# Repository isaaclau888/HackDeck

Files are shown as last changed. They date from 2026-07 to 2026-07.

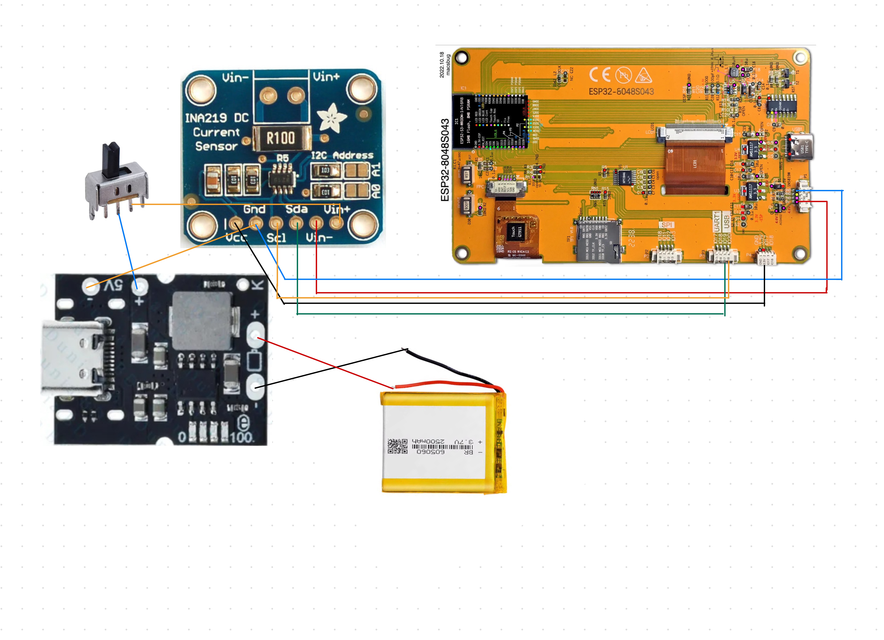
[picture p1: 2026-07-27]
HackDeck Wiring Diagram/HackDeck Wiring Diagram.JPG

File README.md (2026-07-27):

# HackDeck
HackDeck_2026-Jul-26_08-19-04PM-000_CustomizedView14507058763_png

HackDeck is a pocket-sized ESP32 touchscreen tool for testing hardware and checking pinouts.
Firstly, it shows live stats like displays your team’s GitHub updates, Slack messages, and project statuses.
Secondly, it serves as a quick hardware pinout reference and component tester for your workbench.
And last but not least, it lets you touch control custom web/GML tools or games you write for it.

unfold-hackdeck

## How to build it?
Please print all the 3D parts. <p>
螢幕截圖 2026-07-27 上午5 39 52

## How to assemble all the parts?
First, place the screen body down. <p>
螢幕截圖 2026-07-27 上午5 42 49

Secondly, follow the wiring diagram and wire the parts. <p>


1. IP5306 Power Module
 * BAT+: Connect to the Red wire from your LiPo Battery. 
 * BAT-: Connect to the Black wire from your LiPo Battery. 
 * OUT+: Connect to Pin 2 (Middle Pin) of the SS12D07 Slide Switch. (Use 28 AWG wire)
 * OUT-: Connect to GND on the INA219 module. (Use 28 AWG wire)
2. SS12D07 Slide Switch
 * Pin 2 (Middle Pin): Connect to OUT+ on the IP5306 module. (Use 28 AWG wire)
 * Pin 1 or 3 (Side Pin): Connect to VIN+ on the INA219 module. (Use 28 AWG wire)
3. INA219 Sensor Module
 * VIN+: Connect to the Side Pin of the SS12D07 Slide Switch. (Use 28 AWG wire)
 * VIN-: Connect to Port P1, Pin 1 (5V) on the ESP32 board. (Use PicoBlade cable)
 * GND: Connect to OUT- on the IP5306 and to Port P1, Pin 4 (GND) on the ESP32 board. (Use PicoBlade cable)
 * VCC: Connect to Port P4, Pin 2 (3.3V) on the ESP32 board. (Use PicoBlade cable)
 * SDA: Connect to Port P3, Pin 3 (IO19) on the ESP32 board. (Use PicoBlade cable)
 * SCL: Connect to Port P3, Pin 4 (IO20) on the ESP32 board. (Use PicoBlade cable)
4. ESP32-8048S043 Display Board
 * Port P1 (Bottom Centre, next to USB-C):
   * Pin 1 (5V): Wire coming from VIN- on the INA219 module.
   * Pin 4 (GND): Wire coming from GND on the INA219 module.
 * Port P4 (Bottom Left Corner):
   * Pin 2 (3.3V): Wire going to VCC on the INA219 module.
 * Port P3 (Middle Left Edge):
   * Pin 3 (IO19): Wire going to SDA on the INA219 module.
   * Pin 4 (IO20): Wire going to SCL on the INA219 module.
     
Thirdly, place the screen inside the screen body and the parts inside the body. <p>
螢幕截圖 2026-07-27 上午5 54 52

Then, get the screws inside the 4 holes. <p>
螢幕截圖 2026-07-27 上午5 56 02

After that, get the back cover and put it at the back. And also stick the switch and USB-C port out.
螢幕截圖 2026-07-27 上午5 57 08

Finally, you got a complete build.

## How can you use it?
1. Install Arduino IDE
   Download and install the latest version of Arduino IDE from the official Arduino website (https://www.arduino.cc/en/software).
2. Add ESP32 Board Support
   * Open Arduino IDE and go to File > Preferences.
   * In the Additional Boards Manager URLs field, add:
     https://raw.githubusercontent.com/espressif/arduino-esp32/gh-pages/package_esp32_index.json
   * Go to Tools > Board > Boards Manager, search for "ESP32" (by Espressif Systems), and click Install.
3. Install Required Libraries
   * Open the Library Manager (click the book stack icon on the left sidebar).
   * Search for and install the following libraries:
     * LovyanGFX
     * TAMC_GT911
     * ArduinoJson
 4. Configure Board Settings
   - Go to Tools > Board > esp32 > ESP32S3 Dev Module.
   - Configure the following under Tools:
     * USB CDC On Boot: Enabled
     * PSRAM: OPI PSRAM
     * Flash Size: 16MB (128Mb)
     * Partition Scheme: Huge APP (3MB No OTA) or 16M Flash
   - Connect your board via USB-C and select the correct port under Tools > Port.
 5. Upload Firmware
   * Open firmware/HackDeck.ino in Arduino IDE.
   * Update WIFI_SSID, WIFI_PASS, and your webhook URLs at the top of the sketch.
   * Click the Upload button.
 6. You're All Set!
   Once uploading finishes, the board will automatically reboot directly into your desktop control surface!

## Why did I make it?
I decided to make it because I needed a pocket-sized workbench assistant to stop switching tabs and hunting down pinout sheets while prototyping. It puts a live I2C scanner, pinout guide, GitHub feed, and macro buttons right on my desk.

## How I made it?
I designed the custom case using Fusion 360, programmed the firmware in Arduino IDE, and assembled the hardware using the ESP32 screen, IP5306 power management chip, SS12D07 power switch, INA219 current sensor, and a LiPo battery.

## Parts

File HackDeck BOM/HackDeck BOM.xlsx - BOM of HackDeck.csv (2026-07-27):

Description | Item | Usage Count | Purchase Quantity | Unit Price | Subtotal | Price(HKD) [$] | Price(RMB) [$] | Price(USD) [$] | Link | Additional description
Electrical Components
ESP32-8048S043 Display Board |  | 1 | 1 | $167.91 | $167.91 | $167.91 | $145.00 | $21.41 | https://mobile.yangkeduo.com/goods1.html?ps=A4UVhwHh6D
IP5306 Power Module |  | 1 | 1 | $1.68 | $1.68 | $1.68 | $1.45 | $0.21 | https://item.taobao.com/item.htm?id=874907024042&skuId=5709605800856
SS12D07 Slide Switch |  | 1 | 1 | $0.95 | $0.95 | $0.95 | $0.82 | $0.12 | https://item.taobao.com/item.htm?id=568771505825&skuId=6130758858583
INA219 Sensor Module |  | 1 | 1 | $4.59 | $4.59 | $4.59 | $3.96 | $0.58 | https://item.taobao.com/item.htm?id=953659389861
605060 LiPo Battery |  | 1 | 1 | $25.24 | $25.24 | $25.24 | $21.80 | $3.22 | https://item.taobao.com/item.htm?id=578582658189&xxc=shop&skuId=3832117712703
MX1.25 4-Pin Single-End Connector Wire |  | 4 | 1 | $3.13 | $3.13 | $3.13 | $2.70 | $0.40 | https://detail.tmall.com/item.htm?id=576790821801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
28 AWG Wire |  | 1 | 1 | $0.86 | $0.86 | $0.86 | $0.74 | $0.11 | https://detail.tmall.com/item.htm?id=673000932001&xxc=shop&skuId=5022668155483
 |  |  |  | Total |  | $204.36 | $176.47 | $26.05

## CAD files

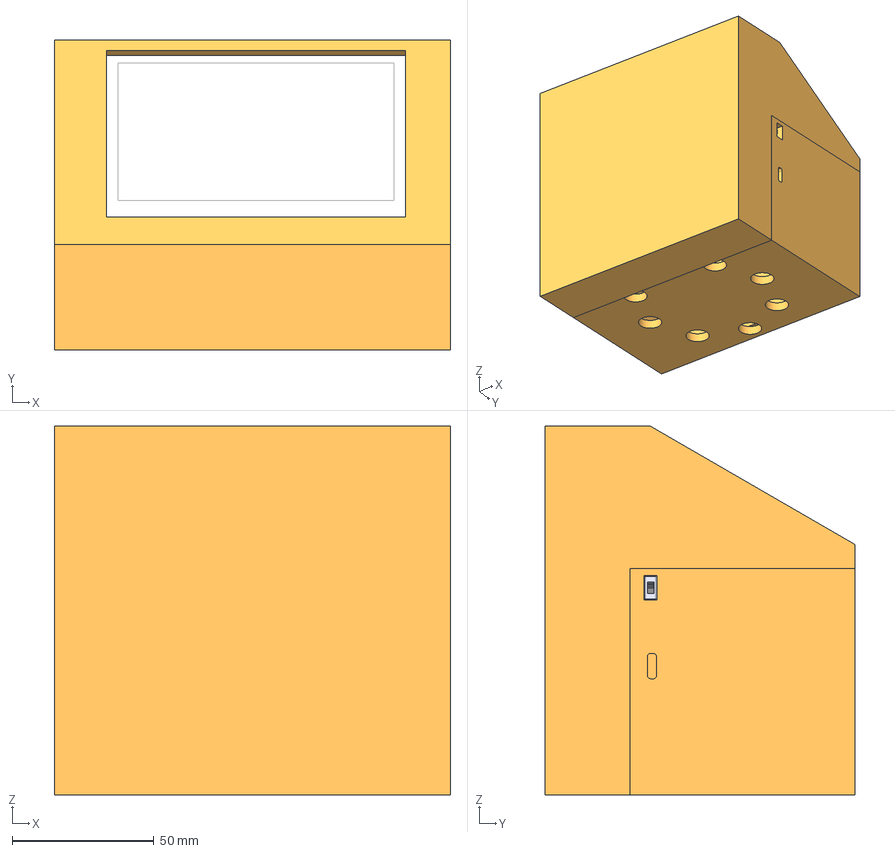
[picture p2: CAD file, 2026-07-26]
HackDeck STEP Files/HackDeck Assembly.step
139.9 x 109.5 x 130.2 mm
Electronics
Screen
Przetwornica 5V 2A
SS12D07VG4
INA219_I2C_IV_SENSOR
605060 LiPo Battery

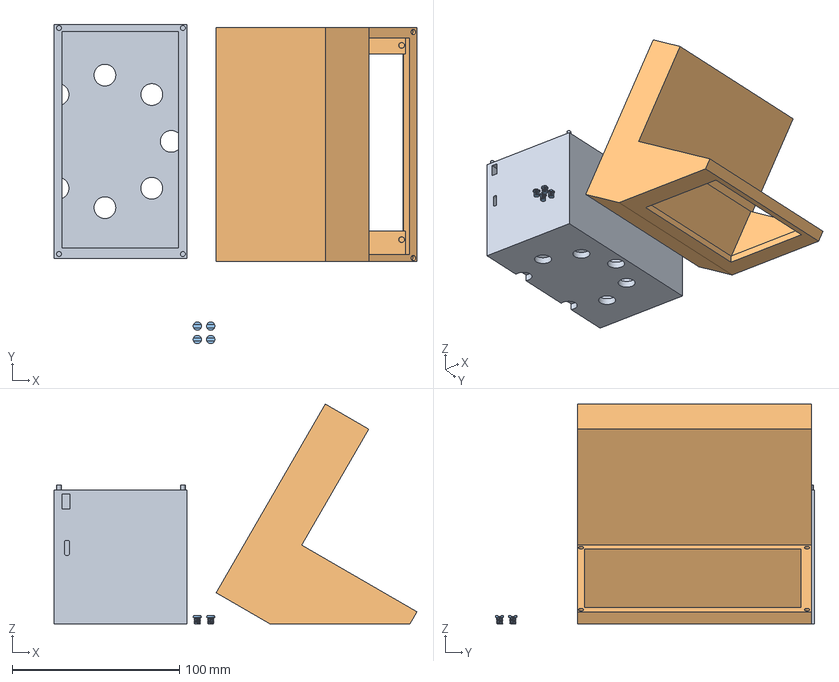
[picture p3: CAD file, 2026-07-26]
HackDeck 3mf File/HackDeck.3mf
216.8 x 190.7 x 131.4 mm
HackDeck Back Case.step
HackDeck Screen Body.step
HackDeck Screws.step

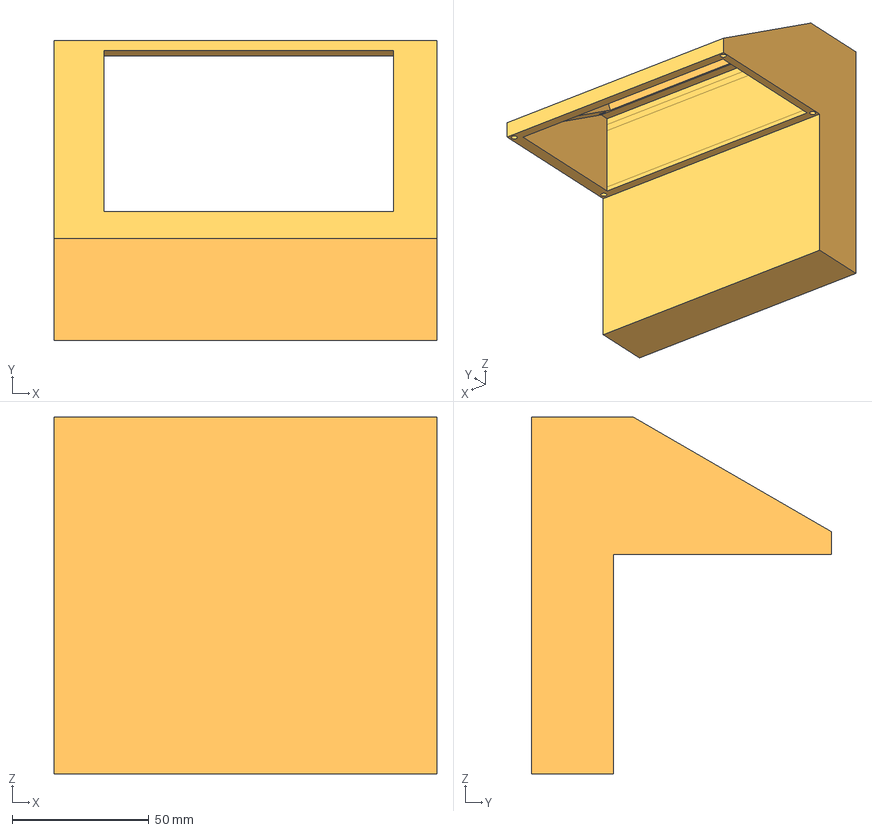
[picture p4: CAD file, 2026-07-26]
HackDeck STEP Files/HackDeck Screen Body.step
139.9 x 109.5 x 130.2 mm

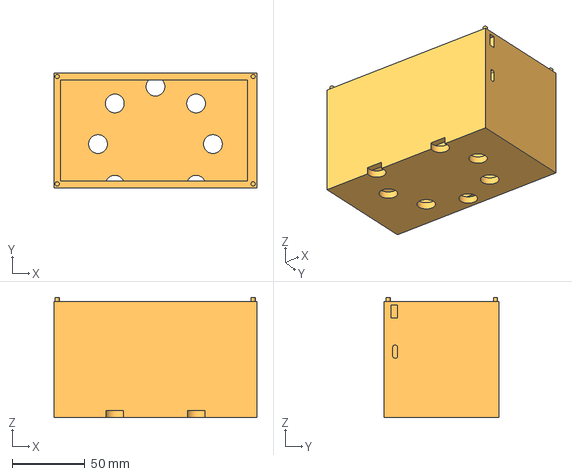
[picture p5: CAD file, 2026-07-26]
HackDeck STEP Files/HackDeck Back Case.step
139.9 x 79.5 x 83.0 mm

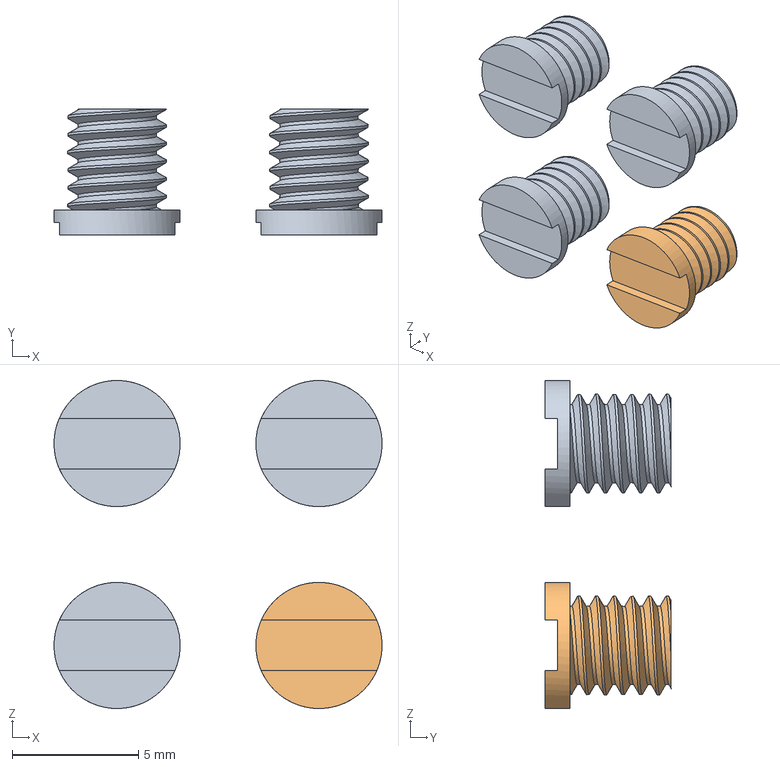
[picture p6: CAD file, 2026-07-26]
HackDeck STEP Files/HackDeck Screws.step
13.0 x 5.00 x 13.0 mm

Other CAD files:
HackDeck F3D/HackDeck.f3z

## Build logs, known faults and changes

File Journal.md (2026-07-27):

## 27/7/2026
I did a lot of work on the same day, spending 4-5 hours building this prototype or maybe the final build? <p>
HackDeck_2026-Jul-26_08-19-04PM-000_CustomizedView14507058763_png 

So why I decided to make this is because I needed a pocket-sized workbench assistant to stop switching tabs and hunting down pinout sheets while prototyping. It puts a live I2C scanner, pinout guide, GitHub feed, and macro buttons right on my desk. <p>

To make this, I made the case in Fusion, and I got all the STEP files of the parts on the Internet. Finding the parts on Google is tough; I need to think which parts I need and which parts I don't need. <p>
螢幕截圖 2026-07-27 上午11 15 11

After I made the case, I did the wiring diagram, and it looks like this: <p>
HackDeck Wiring Diagram
It doesn't look bad anyway. <p>

After making the wiring diagram, I have to do the BOM. I found the parts on Taobao. <p>
螢幕截圖 2026-07-27 上午11 17 45

Then, for the STEP files and the F3D, I exported them and put them in files. <p>
螢幕截圖 2026-07-27 上午11 19 40

For printing the parts, I imported the STEP files into the 3mf file for me to print them out on my 3D printer. <p>
螢幕截圖 2026-07-27 上午5 39 52

Last but not least, I dealt with README.md and Journal.md. This is the Journal.md that you are reading, and the README.md is on the front page of this repo. <p>
螢幕截圖 2026-07-27 上午11 22 26

What I did wrong was that when I was making the screws, I forgot to click the modelled button, and after I imported it to Bambu Studio, it didn't show the curves. <p>
螢幕截圖 2026-07-27 上午11 23 38

This is what I did today.

Total Time: 6 hours and 10 mins
https://lapse.hackclub.com/timelapse/nYyScDbP78Ud

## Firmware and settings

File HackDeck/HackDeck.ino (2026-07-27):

#include <Arduino.h>
#include <Wire.h>
#include <WiFi.h>
#include <TAMC_GT911.h>

#define LGFX_USE_V1
#include <LovyanGFX.hpp>
#include <lgfx/v1/platforms/esp32s3/Panel_RGB.hpp>
#include <lgfx/v1/platforms/esp32s3/Bus_RGB.hpp>
#include <HTTPClient.h>
#include <ArduinoJson.h>

// --- Wi-Fi Configuration (FILL THESE IN!) ---
const char* WIFI_SSID = "YOUR_WIFI_NAME";
const char* WIFI_PASS = "YOUR_WIFI_PASSWORD";
const char* SLACK_WEBHOOK_URL = "https://hooks.slack.com/services/YOUR/SLACK/WEBHOOK_URL";

// --- Hardware Pins ---
#define I2C_SDA 19
#define I2C_SCL 20
#define TOUCH_INT -1
#define TOUCH_RST -1
#define TOUCH_WIDTH  800
#define TOUCH_HEIGHT 480

// --- Global Data Variables ---
String i2cResults[16]; 
int i2cDeviceCount = -1;

String githubUser = "isaaclau888"; 
int publicRepos = 0;
int followersCount = 0;
String lastCommitMsg = "Fetching...";
unsigned long lastDataFetch = 0;

bool wifiConnected = false;
unsigned long lastWifiCheck = 0;

// --- Display Sleep & Backlight Management ---
unsigned long lastActivityTime = 0;
const unsigned long DIM_TIMEOUT   = 30000;  // 30 sec
const unsigned long SLEEP_TIMEOUT = 120000; // 2 min

enum ScreenPowerState { BRIGHT, DIMMED, OFF };
ScreenPowerState powerState = BRIGHT;

// --- Display Driver Setup ---
class LGFX : public lgfx::LGFX_Device {
  lgfx::Panel_RGB _panel_instance;
  lgfx::Bus_RGB   _bus_instance;
  lgfx::Light_PWM _light_instance;

public:
  LGFX() {
    {
      auto cfg = _bus_instance.config();
      cfg.panel = &_panel_instance;
      
      cfg.pin_d0  = 8;   cfg.pin_d1  = 3;   cfg.pin_d2  = 46;  cfg.pin_d3  = 9;
      cfg.pin_d4  = 1;   cfg.pin_d5  = 5;   cfg.pin_d6  = 6;   cfg.pin_d7  = 7;
      cfg.pin_d8  = 15;  cfg.pin_d9  = 16;  cfg.pin_d10 = 4;   cfg.pin_d11 = 45;
      cfg.pin_d12 = 48;  cfg.pin_d13 = 47;  cfg.pin_d14 = 21;  cfg.pin_d15 = 14;
      
      cfg.pin_henable = 40; 
      cfg.pin_vsync   = 41;
      cfg.pin_hsync   = 39;
      cfg.pin_pclk    = 42;
      cfg.freq_write  = 14000000;
      
      cfg.hsync_polarity    = 0; cfg.hsync_front_porch = 8;
      cfg.hsync_pulse_width = 4; cfg.hsync_back_porch  = 16;
      cfg.vsync_polarity    = 0; cfg.vsync_front_porch = 4;
      cfg.vsync_pulse_width = 4; cfg.vsync_back_porch  = 4;
      cfg.pclk_idle_high    = 1;
      
      _bus_instance.config(cfg);
      _panel_instance.setBus(&_bus_instance);
    }
    {
      auto cfg = _panel_instance.config();
      cfg.memory_width  = 800; cfg.memory_height = 480;
      cfg.panel_width   = 800; cfg.panel_height  = 480;
      cfg.offset_x      = 0;   cfg.offset_y      = 0;
      _panel_instance.config(cfg);
    }
    {
      auto cfg = _panel_instance.config_detail();
      cfg.use_psram = 1;
      _panel_instance.config_detail(cfg);
    }
    {
      auto cfg = _light_instance.config();
      cfg.pin_bl = 2;
      _light_instance.config(cfg);
      _panel_instance.setLight(&_light_instance);
    }
    setPanel(&_panel_instance);
  }
};

LGFX lcd;
TAMC_GT911 ts = TAMC_GT911(I2C_SDA, I2C_SCL, TOUCH_INT, TOUCH_RST, TOUCH_WIDTH, TOUCH_HEIGHT);

enum AppScreen { DASHBOARD, PINOUT, CONTROLLER };
AppScreen currentScreen = DASHBOARD;
unsigned long lastTouchTime = 0;

void setScreenPower(ScreenPowerState state) {
  if (powerState == state) return;
  powerState = state;
  switch (state) {
    case BRIGHT: lcd.setBrightness(180); break;
    case DIMMED: lcd.setBrightness(30);  break;
    case OFF:    lcd.setBrightness(0);   break;
  }
}

void drawNavBar() {
  lcd.fillRect(0, 0, 800, 50, lcd.color565(30, 30, 30));
  
  // Dashboard
  lcd.fillRect(10, 5, 210, 40, currentScreen == DASHBOARD ? lcd.color565(0, 150, 255) : lcd.color565(60, 60, 60));
  lcd.setTextColor(TFT_WHITE);
  lcd.setTextSize(2);
  lcd.drawString("DASHBOARD", 50, 15);

  // Pinout
  lcd.fillRect(225, 5, 210, 40, currentScreen == PINOUT ? lcd.color565(0, 200, 100) : lcd.color565(60, 60, 60));
  lcd.drawString("PINOUT", 290, 15);

  // Controller
  lcd.fillRect(445, 5, 210, 40, currentScreen == CONTROLLER ? lcd.color565(255, 120, 0) : lcd.color565(60, 60, 60));
  lcd.drawString("CONTROLLER", 490, 15);

  // Wi-Fi Status Box
  if (WiFi.status() == WL_CONNECTED) {
    lcd.fillRoundRect(665, 8, 125, 34, 6, lcd.color565(0, 180, 80));
    lcd.setTextSize(1);
    lcd.drawString("Wi-Fi OK", 700, 20);
  } else {
    lcd.fillRoundRect(665, 8, 125, 34, 6, lcd.color565(200, 50, 50));
    lcd.setTextSize(1);
    lcd.drawString("Connecting...", 680, 20);
  }
}

void fetchGitHubData() {
  if (WiFi.status() != WL_CONNECTED) return;

  HTTPClient http;
  String url = "https://api.github.com/users/" + githubUser;
  
  http.begin(url);
  http.setUserAgent("ESP32-HackDeck");
  int httpCode = http.GET();

  if (httpCode == HTTP_CODE_OK) {
    String payload = http.getString();
    JsonDocument doc;
    DeserializationError error = deserializeJson(doc, payload);

    if (!error) {
      publicRepos = doc["public_repos"] | 0;
      followersCount = doc["followers"] | 0;
      lastCommitMsg = "Data Sync OK!";
    }
  } else {
    lastCommitMsg = "HTTP Error: " + String(httpCode);
  }
  http.end();
}

void sendWebhook(String actionName) {
  if (WiFi.status() != WL_CONNECTED) {
    Serial.println("Cannot send webhook: Wi-Fi disconnected");
    return;
  }

  HTTPClient http;
  http.begin(SLACK_WEBHOOK_URL);
  http.addHeader("Content-Type", "application/json");
  
  String payload = "{\"text\":\"*HackDeck Alert:* Triggered `" + actionName + "` from workbench!\"}";
  int httpCode = http.POST(payload);

  if (httpCode == 200) {
    Serial.println("Slack notification sent successfully!");
  } else {
    Serial.printf("Slack HTTP Error: %d\n", httpCode);
  }
  http.end();
}

void scanI2CBus() {
  i2cDeviceCount = 0;
  for (int i = 0; i < 16; i++) i2cResults[i] = "";

  for (byte address = 1; address < 127; address++) {
    Wire.beginTransmission(address);
    byte error = Wire.endTransmission();

    if (error == 0) {
      if (i2cDeviceCount < 16) {
        char hexBuffer[10];
        sprintf(hexBuffer, "0x%02X", address);
        i2cResults[i2cDeviceCount] = String(hexBuffer);
        i2cDeviceCount++;
      }
    }
  }
}

void drawScreenContent() {
  lcd.fillRect(0, 51, 800, 429, TFT_BLACK);

  if (currentScreen == DASHBOARD) {
    lcd.setTextColor(TFT_WHITE);
    lcd.setTextSize(2);
    lcd.drawString("HackDeck Live Feed", 30, 75);

    // Card 1: GitHub
    lcd.fillRoundRect(30, 110, 350, 180, 10, lcd.color565(20, 25, 35));
    lcd.drawRoundRect(30, 110, 350, 180, 10, lcd.color565(0, 150, 255));
    lcd.setTextColor(lcd.color565(0, 150, 255));
    lcd.drawString("GitHub: @" + githubUser, 50, 130);

    lcd.setTextColor(TFT_WHITE);
    lcd.drawString("Public Repos: " + String(publicRepos), 50, 170);
    lcd.drawString("Followers:    " + String(followersCount), 50, 205);
    
    lcd.setTextSize(1);
    lcd.setTextColor(lcd.color565(180, 180, 180));
    lcd.drawString("Status: " + lastCommitMsg, 50, 250);

    // Card 2: MakerTeam
    lcd.setTextSize(2);
    lcd.fillRoundRect(420, 110, 350, 180, 10, lcd.color565(20, 25, 35));
    lcd.drawRoundRect(420, 110, 350, 180, 10, lcd.color565(0, 200, 100));
    lcd.setTextColor(lcd.color565(0, 200, 100));
    lcd.drawString("MakerTeam Feed", 440, 130);

    lcd.setTextColor(TFT_WHITE);
    lcd.drawString("Status: Active", 440, 170);
    lcd.drawString("Mode: Connected", 440, 205);

    // Telemetry Footer
    lcd.fillRoundRect(30, 310, 740, 110, 10, lcd.color565(25, 25, 25));
    lcd.drawRoundRect(30, 310, 740, 110, 10, lcd.color565(100, 100, 100));
    lcd.drawString("System Telemetry", 50, 330);
    lcd.drawString("IP: " + (WiFi.status() == WL_CONNECTED ? WiFi.localIP().toString() : String("Offline")), 50, 370);

  } else if (currentScreen == PINOUT) {
    lcd.setTextColor(TFT_WHITE);
    lcd.setTextSize(2);
    lcd.drawString("Workbench Hardware Reference", 30, 75);

    // Pinout Card
    lcd.fillRoundRect(30, 110, 350, 310, 10, lcd.color565(20, 25, 35));
    lcd.drawRoundRect(30, 110, 350, 310, 10, lcd.color565(0, 200, 100));
    lcd.setTextColor(lcd.color565(0, 200, 100));
    lcd.drawString("On-Board Pinout", 50, 130);

    lcd.setTextSize(1);
    lcd.setTextColor(TFT_WHITE);
    lcd.drawString("I2C SDA:     GPIO 19", 50, 170);
    lcd.drawString("I2C SCL:     GPIO 20", 50, 195);
    lcd.drawString("PWM Dimmer:  GPIO 2",  50, 220);
    lcd.drawString("RGB HENABLE: GPIO 40", 50, 245);
    lcd.drawString("RGB VSYNC:   GPIO 41", 50, 270);
    lcd.drawString("RGB HSYNC:   GPIO 39", 50, 295);
    lcd.drawString("RGB PCLK:    GPIO 42", 50, 320);

    // I2C Scanner Card
    lcd.setTextSize(2);
    lcd.fillRoundRect(420, 110, 350, 310, 10, lcd.color565(20, 25, 35));
    lcd.drawRoundRect(420, 110, 350, 310, 10, lcd.color565(255, 180, 0));
    lcd.setTextColor(lcd.color565(255, 180, 0));
    lcd.drawString("Live I2C Bus Scan", 440, 130);

    // SCAN Button
    lcd.fillRoundRect(440, 165, 140, 40, 8, lcd.color565(0, 150, 255));
    lcd.setTextColor(TFT_WHITE);
    lcd.setTextSize(2);
    lcd.drawString("SCAN", 480, 177);

    lcd.setTextSize(1);
    lcd.setTextColor(TFT_WHITE);
    if (i2cDeviceCount == -1) {
      lcd.drawString("Tap SCAN to check I2C bus...", 440, 225);
    } else if (i2cDeviceCount == 0) {
      lcd.setTextColor(lcd.color565(255, 100, 100));
      lcd.drawString("No external devices found!", 440, 225);
    } else {
      lcd.setTextColor(lcd.color565(0, 255, 150));
      lcd.drawString("Found " + String(i2cDeviceCount) + " device(s):", 440, 220);
      
      int startY = 250;
      for (int i = 0; i < i2cDeviceCount; i++) {
        int col = i % 3;
        int row = i / 3;
        lcd.drawString(i2cResults[i], 440 + (col * 90), startY + (row * 30));
      }
    }

    lcd.setTextColor(lcd.color565(180, 180, 180));
    lcd.drawString("---------------------------------", 440, 360);
    lcd.drawString("Logic Level: 3.3V ONLY | GPIO 19/20", 440, 385);

  } else if (currentScreen == CONTROLLER) {
    lcd.setTextColor(TFT_WHITE);
    lcd.setTextSize(2);
    lcd.drawString("Touch Macro Control Surface", 30, 80);

    lcd.fillRoundRect(50, 150, 200, 120, 12, lcd.color565(255, 120, 0));
    lcd.drawString("Action A", 90, 200);

    lcd.fillRoundRect(300, 150, 200, 120, 12, lcd.color565(255, 120, 0));
    lcd.drawString("Action B", 340, 200);

    lcd.fillRoundRect(550, 150, 200, 120, 12, lcd.color565(255, 120, 0));
    lcd.drawString("Action C", 590, 200);
  }
}

void setup() {
  Serial.begin(115200);

  // Initialize display first
  lcd.init();
  setScreenPower(BRIGHT);
  lcd.fillScreen(TFT_BLACK);

  // Correct order for GT911 touch bus init
  Wire.begin(I2C_SDA, I2C_SCL);
  ts.begin();
  ts.setRotation(ROTATION_NORMAL);

  lastActivityTime = millis();

  // Start background Wi-Fi connection
  WiFi.mode(WIFI_STA);
  WiFi.begin(WIFI_SSID, WIFI_PASS);

  drawNavBar();
  drawScreenContent();
}

void loop() {
  ts.read();
  
  if (ts.isTouched) {
    lastActivityTime = millis();
    
    if (powerState != BRIGHT) {
      setScreenPower(BRIGHT);
      delay(200);
      return;
    }

    if (millis() - lastTouchTime > 250) {
      int touchX = ts.points[0].x;
      int touchY = ts.points[0].y;
      lastTouchTime = millis();

      // Top Nav Bar
      if (touchY < 50) {
        if (touchX < 225) {
          currentScreen = DASHBOARD;
        } else if (touchX >= 225 && touchX < 445) {
          currentScreen = PINOUT;
        } else if (touchX >= 445 && touchX < 665) {
          currentScreen = CONTROLLER;
        }
        drawNavBar();
        drawScreenContent();
      }
      // Scan Button
      else if (currentScreen == PINOUT) {
        if (touchX >= 440 && touchX <= 580 && touchY >= 165 && touchY <= 205) {
          lcd.fillRoundRect(440, 165, 140, 40, 8, lcd.color565(0, 200, 100));
          lcd.setTextColor(TFT_WHITE);
          lcd.setTextSize(2);
          lcd.drawString("SCANNING", 455, 177);
          
          scanI2CBus();
          delay(150);
          drawScreenContent();
        }
      }
      // Controller Macros
      else if (currentScreen == CONTROLLER) {
        if (touchY >= 150 && touchY <= 270) {
          if (touchX >= 50 && touchX <= 250) {
            sendWebhook("Action A");
          } else if (touchX >= 300 && touchX <= 500) {
            sendWebhook("Action B");
          } else if (touchX >= 550 && touchX <= 750) {
            sendWebhook("Action C");
          }
        }
      }
    }
  }

  // Idle Screen Dimming & Sleep
  unsigned long idleTime = millis() - lastActivityTime;
  if (idleTime > SLEEP_TIMEOUT) {
    setScreenPower(OFF);
  } else if (idleTime > DIM_TIMEOUT) {
    setScreenPower(DIMMED);
  }

  // Auto-fetch GitHub telemetry every 30s
  if (powerState != OFF && currentScreen == DASHBOARD && (millis() - lastDataFetch > 30000 || lastDataFetch == 0)) {
    lastDataFetch = millis();
    fetchGitHubData();
    drawScreenContent();
  }

  // Non-blocking Wi-Fi reconnect monitor
  if (millis() - lastWifiCheck > 3000) {
    lastWifiCheck = millis();
    bool currentStatus = (WiFi.status() == WL_CONNECTED);
    if (currentStatus != wifiConnected) {
      wifiConnected = currentStatus;
      drawNavBar();
    }
  }

  delay(20);
}
